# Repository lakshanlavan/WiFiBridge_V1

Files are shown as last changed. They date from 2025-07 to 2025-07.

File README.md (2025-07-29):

# 📶 WiFiBridge V1

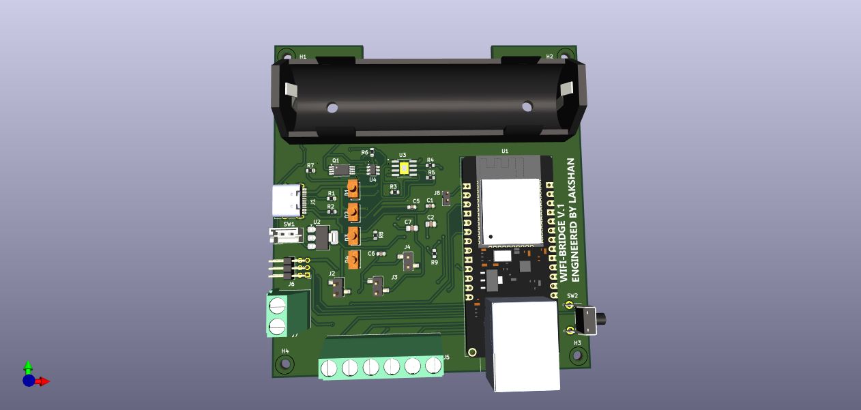
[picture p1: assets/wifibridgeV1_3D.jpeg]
WiFiBridge 3D View


### 🔧 Project Overview

**WiFiBridge V1** is a compact, battery-powered Wi-Fi bridge designed by **Lakshan Lavan**.  
It leverages the **WT32-ETH01 WiFi module** and features power-efficient circuitry, UART-based communication, and robust modularity for IoT and automation tasks.

---

## 🧩 Key Features

- ✅ WT32-ETH01 (ESP32-based WiFi + Ethernet module)
- 🔋 18650 battery integration for mobile applications
- 💡 LED indicators for:
  - Power status
  - WiFi connectivity
  - Battery charging and full charge
- 📤 Pick-and-place ready with `.csv` top position file
- 🪛 Custom KiCad footprints for modular components
- 🧠 Designed for compact routing and easy assembly

---

## 🏭 Fabrication Notes

- ✅ No Gerbers are published.  
  You can open the `.kicad_pcb` file in [KiCad](https://kicad.org/) to generate fabrication files if needed.
- Designed with **JLCPCB component compatibility** in mind.
- Supports **SMD assembly** using `.csv` pick-and-place file.

---

## ⚠️ Disclaimer

This project is open-source and provided as-is. Modify, improve, or integrate it freely into your own systems.

---

## 👤 Author

**Lakshan Lavan**  
Embedded Systems | Robotics | PCB Design  
[LinkedIn](https://www.linkedin.com/in/lakshan29) | [Email](mailto:lakshanlavan29@gmail.com)

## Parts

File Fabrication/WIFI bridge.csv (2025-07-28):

Comment | Designator | Footprint | JLCPCB part #
Battery_Cell | BT1 | Battery:BatteryHolder_MPD_BH-18650-PC2 | C9900045649
10u | C1, C6 | Capacitor_SMD:C_0603_1608Metric | C1713
22u | C2 | Capacitor_SMD:C_0805_2012Metric | C29277
100n | C5 | Capacitor_SMD:C_0603_1608Metric | C1590
100n | C7 | Capacitor_SMD:C_0805_2012Metric_Pad1.18x1.45mm_HandSolder | C1590
LED | D1, D2, D3, D4 | LED_THT:LED_D2.0mm_W4.8mm_H2.5mm_FlatTop
USB_C_Receptacle_USB2.0_16P | J1 | Connector_USB:USB_C_Receptacle_HRO_TYPE-C-31-M-12 | C165948
+- | J2 | Connector_PinHeader_2.54mm:PinHeader_1x02_P2.54mm_Vertical_SMD_Pin1Left
1B+2B- | J3 | Connector_PinHeader_2.54mm:PinHeader_1x02_P2.54mm_Vertical_SMD_Pin1Left
1OUT+2OUT- | J4 | Connector_PinHeader_2.54mm:PinHeader_1x02_P2.54mm_Vertical_SMD_Pin1Left
Screw_Terminal_01x06 | J5 | TerminalBlock_Phoenix:TerminalBlock_Phoenix_MKDS-1,5-6-5.08_1x06_P5.08mm_Horizontal | C89120
Screw_Terminal_01x07 | J6 | Connector_PinHeader_2.00mm:PinHeader_2x03_P2.00mm_Horizontal | C32713227
Screw_Terminal_01x08 | J7 | TerminalBlock_Phoenix:TerminalBlock_Phoenix_MKDS-1,5-2_1x02_P5.00mm_Horizontal | C89120
Screw_Terminal_01x09 | J8 | Connector_PinHeader_2.00mm:PinHeader_1x02_P2.00mm_Vertical | C22438285
Screw_Terminal_01x10 | Q1 | Package_SO:TSSOP-8_4.4x3mm_P0.65mm | C16052
Screw_Terminal_01x11 | R1, R2 | Resistor_SMD:R_0603_1608Metric | C3202451
Screw_Terminal_01x12 | R3 | Resistor_SMD:R_0603_1608Metric | C100050
Screw_Terminal_01x13 | R4, R5, R7 | Resistor_SMD:R_0603_1608Metric | C73797
Screw_Terminal_01x14 | R6 | Resistor_SMD:R_0603_1608Metric | C7250
Screw_Terminal_01x15 | R8 | Resistor_SMD:R_0603_1608Metric | C23096
Screw_Terminal_01x16 | R9 | Resistor_SMD:R_0603_1608Metric | C1203
Screw_Terminal_01x17 | SW1 | Connector_JST:JST_EH_B2B-EH-A_1x02_P2.50mm_Vertical | C160262
Screw_Terminal_01x18 | SW2 | Button_Switch_THT:SW_Tactile_SPST_Angled_PTS645Vx58-2LFS | C2837546
Screw_Terminal_01x19 | U1 | Library:WT32-ETH01
Screw_Terminal_01x20 | U2 | Package_TO_SOT_SMD:SOT-223-3_TabPin2 | C6186
Screw_Terminal_01x21 | U3 | Library:SOP127P600X175-9N | C382139
Screw_Terminal_01x22 | U4 | Package_TO_SOT_SMD:SOT-23-6 | C351410

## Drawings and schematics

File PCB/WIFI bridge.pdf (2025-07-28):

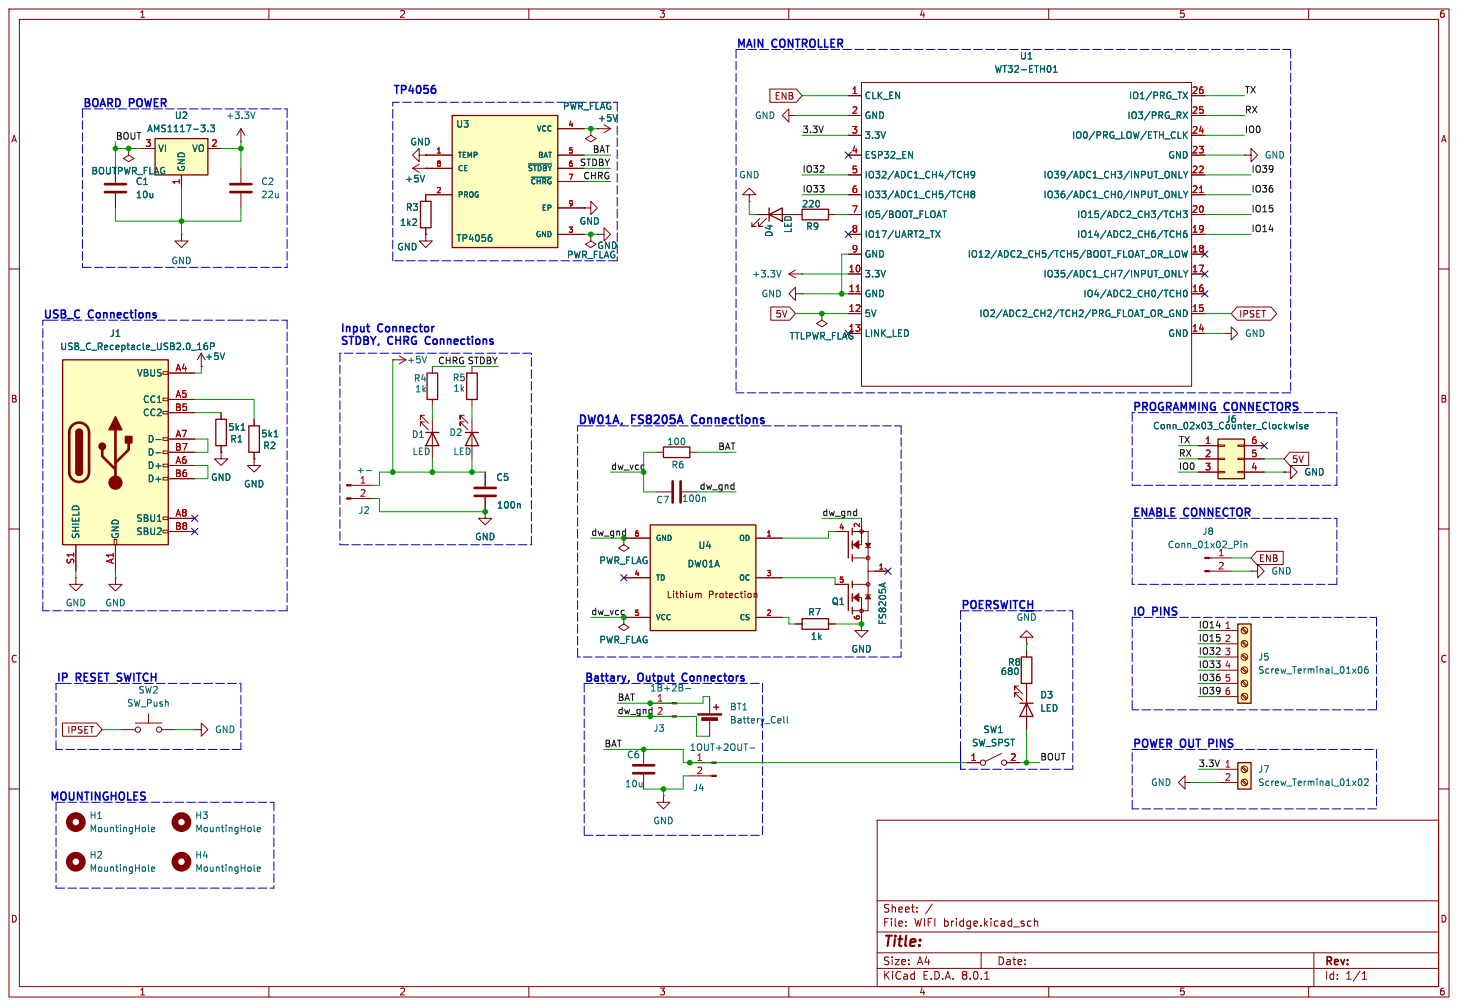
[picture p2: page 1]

Input Connector STDBY, CHRG Connections

Battary, Output Connectors DW01A, FS8205A Connections

IP RESET SWITCH MOUNTINGHOLES

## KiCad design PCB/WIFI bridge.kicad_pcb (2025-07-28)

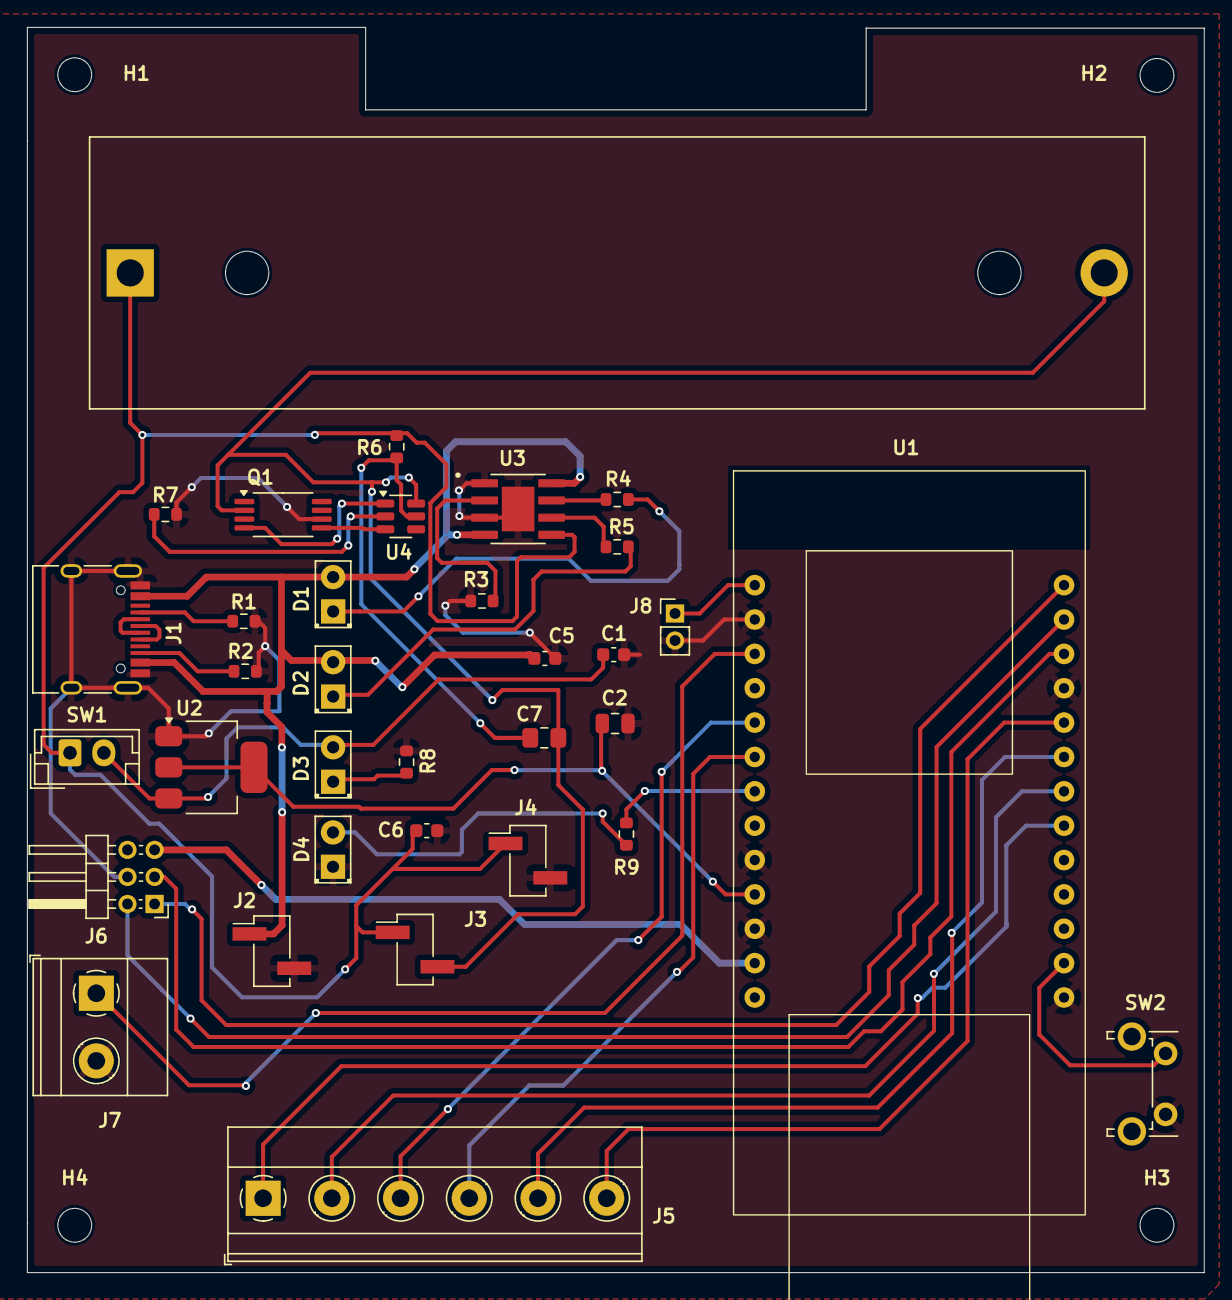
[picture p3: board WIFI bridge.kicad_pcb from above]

Board: 2 copper layers, 87.0 x 92.0 mm, 38 parts (0 on the bottom side), 35 nets.

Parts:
BT1: Battery_Cell; BatteryHolder_MPD_BH-18650-PC2
C1, C6: 10u; C_0603_1608Metric
C2: 22u; C_0805_2012Metric
C5: 100n; C_0603_1608Metric
C7: 100n; C_0805_2012Metric_Pad1.18x1.45mm_HandSolder
D1, D2, D3, D4: LED; LED_D2.0mm_W4.8mm_H2.5mm_FlatTop
H1, H2, H3, H4: MountingHole; MountingHole_2.5mm
J1: USB_C_Receptacle_USB2.0_16P; USB_C_Receptacle_HRO_TYPE-C-31-M-12
J2: +-; PinHeader_1x02_P2.54mm_Vertical_SMD_Pin1Left
J3: 1B+2B-; PinHeader_1x02_P2.54mm_Vertical_SMD_Pin1Left
J4: 1OUT+2OUT-; PinHeader_1x02_P2.54mm_Vertical_SMD_Pin1Left
J5: Screw_Terminal_01x06; TerminalBlock_Phoenix_MKDS-1,5-6-5.08_1x06_P5.08mm_Horizont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
J6: Conn_02x03_Counter_Clockwise; PinHeader_2x03_P2.00mm_Horizontal
J7: Screw_Terminal_01x02; TerminalBlock_Phoenix_MKDS-1,5-2_1x02_P5.00mm_Horizontal
J8: Conn_01x02_Pin; PinHeader_1x02_P2.00mm_Vertical
Q1: FS8205A; TSSOP-8_4.4x3mm_P0.65mm
R1, R2: 5k1; R_0603_1608Metric
R3: 1k2; R_0603_1608Metric
R4, R5, R7: 1k; R_0603_1608Metric
R6: 100; R_0603_1608Metric
R8: 680; R_0603_1608Metric
R9: 220; R_0603_1608Metric
SW1: SW_SPST; JST_EH_B2B-EH-A_1x02_P2.50mm_Vertical
SW2: SW_Push; SW_Tactile_SPST_Angled_PTS645Vx58-2LFS
U1: WT32-ETH01
U2: AMS1117-3.3; SOT-223-3_TabPin2
U3: TP4056; SOP127P600X175-9N
U4: DW01A; SOT-23-6

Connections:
5V: J6.5, U1.12 (5V)
+3.3V: C2.1, U1.10 (3.3V), U2.2 (VO)
+5V: C5.1, D1.2 (A), D2.2 (A), J1.A4 (VBUS), J1.A9 (VBUS), J1.B4 (VBUS), J1.B9 (VBUS), J2.1, U3.4 (VCC), U3.8 (CE)
/3.3V: J7.1, U1.3 (3.3V)
/BAT: BT1.1 (+), C6.1, J3.1, J4.1, R6.2, SW1.1 (A), U3.5 (BAT)
/BOUT: C1.1, D3.2 (A), SW1.2 (B), U2.3 (VI)
/CHRG: R4.1, U3.7 (~CHRG)
/IO0: J6.3, U1.24 (IO0/PRG_LOW/ETH_CLK)
/IO14: J5.1, U1.19 (IO14/ADC2_CH6/TCH6)
/IO15: J5.2, U1.20 (IO15/ADC2_CH3/TCH3)
/IO32: J5.3, U1.5 (IO32/ADC1_CH4/TCH9)
/IO33: J5.4, U1.6 (IO33/ADC1_CH5/TCH8)
/IO36: J5.5, U1.21 (IO36/ADC1_CH0/INPUT_ONLY)
/IO39: J5.6, U1.22 (IO39/ADC1_CH3/INPUT_ONLY)
/RX: J6.2, U1.25 (IO3/PRG_RX)
/STDBY: R5.1, U3.6 (~STDBY)
/TX: J6.1, U1.26 (IO1/PRG_TX)
/dw_gnd: BT1.2 (-), C7.2, J3.2, Q1.2, U4.6 (GND)
/dw_vcc: C7.1, R6.1, U4.5 (VCC)
ENB: J8.1, U1.1 (CLK_EN)
GND: C1.2, C2.2, C5.2, C6.2, D4.1 (K), J1.A1 (GND), J1.A12 (GND), J1.B1 (GND), J1.B12 (GND), J1.S1 (SHIELD), J2.2, J4.2, J6.4, J7.2, J8.2, Q1.6, R1.2, R2.2, R3.1, R7.2, R8.1, SW2.2, U1.2 (GND), U1.9 (GND), U1.11 (GND), U1.14 (GND), U1.23 (GND), U2.1 (GND), U3.1 (TEMP), U3.3 (GND), U3.9 (EP)
IPSET: SW2.1, U1.15 (IO2/ADC2_CH2/TCH2/PRG_FLOAT_OR_GND)
unnamed: D1.1 (K), R4.2
unnamed: D2.1 (K), R5.2
unnamed: D3.1 (K), R8.2
unnamed: D4.2 (A), R9.1
unnamed: J1.A5 (CC1), R1.1
unnamed: J1.B5 (CC2), R2.1
unnamed: J1.A6 (D+), J1.B6 (D+)
unnamed: J1.A7 (D-), J1.B7 (D-)
unnamed: R9.2, U1.7 (IO5/BOOT_FLOAT)
unnamed: R3.2, U3.2 (PROG)
unnamed: R7.1, U4.2 (CS)
unnamed: Q1.5, U4.3 (OC)
unnamed: Q1.4, U4.1 (OD)
